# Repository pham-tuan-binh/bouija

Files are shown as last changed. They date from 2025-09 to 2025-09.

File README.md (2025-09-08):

# Bouija

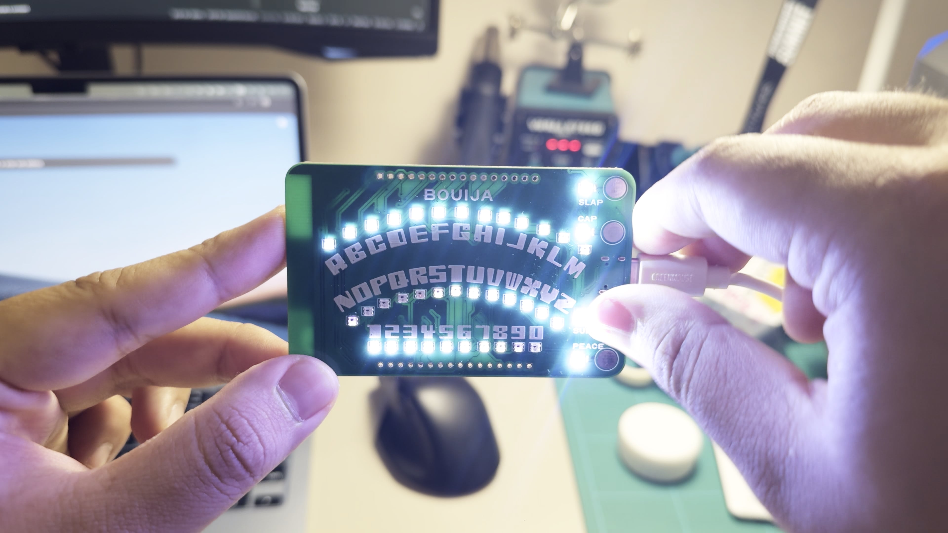
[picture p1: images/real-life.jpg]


A PCB business card that runs an LLM locally with an Ouija board-inspired LED layout.

Watch a video on the design of this business card [here](https://youtu.be/WC3O2cKT8Eo).

**Special thanks to NextPB for sponsoring this project. Check out their website [here](https://www.nextpcb.com?code=Build_With_Binh)**

## Overview

Bouija is a unique business card featuring an ESP32-S3 that runs a local Large Language Model. The device uses 40 individually addressable WS2812B LEDs arranged in an Ouija board pattern to visualize text generation in real-time.

## Specifications

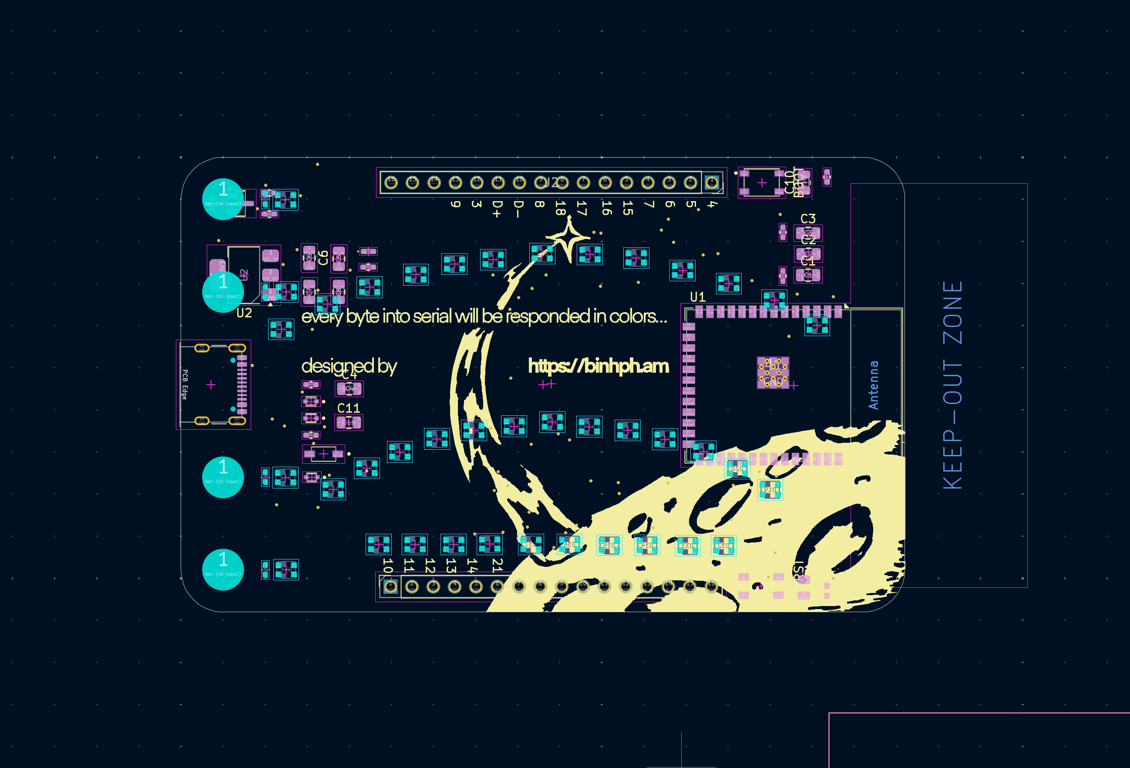
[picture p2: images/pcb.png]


- **PCB Dimensions**: 85mm × 54mm with 3mm corner radius
- **LEDs**: 40 WS2812B LEDs
  - 26 letters (A-Z)
  - 10 numbers (0-9)
  - 4 shortcuts: cap, slap, peace, sup
- **MCU**: ESP32-S3 with 8MB PSRAM and 16MB Flash
- **Layout**: Ouija board arrangement for cultural authenticity

## Firmware Options

### Simple Mode (`/firmware/simple`)

Hard-coded messages with LED visualization and touch interaction.

### LLM Mode (`/firmware/tinyllama`)

Local LLM text generation using [Dave Bennett's ESP32 LLM implementation](https://github.com/DaveBben/esp32-llm). Credit to Dave Bennett for the LLM core - I added the visualization and interaction layer.

## Setup

Requires ESP-IDF toolchain:

```bash
# Navigate to desired firmware directory
cd firmware/tinyllama  # or firmware/simple

# Build and flash
idf.py build
idf.py -p /dev/{DEVICE_PORT} flash
```

## Hardware

The PCB design is available in `/pcb` as a KiCad project.

## Why "Bouija"?

It's a play on "Ouija" + "Binh" (the creator's name) - because what's a business card without a little wordplay? 👻

---

_Running AI on a business card because why not?_

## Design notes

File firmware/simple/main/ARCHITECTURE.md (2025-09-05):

# Code Architecture

This document describes the modular architecture of the ESP32 LED Board Application.

## Module Structure

### 1. **main.c** - Application Entry Point

- **Responsibility**: Application initialization and startup
- **Dependencies**: led.h, app_flow.h
- **Functions**:
  - `app_main()`: Initializes LED strip, sets brightness, and starts application flow

### 2. **led.h/led.c** - LED Hardware Abstraction Layer

- **Responsibility**: LED strip control and animations
- **Dependencies**: ESP-IDF LED strip driver, FreeRTOS
- **Key Functions**:
  - `led_init()`: Initialize LED strip hardware
  - `led_set_led()`: Set individual LED color
  - `led_clear_all()`: Turn off all LEDs
  - `led_show_loading_sequence()`: Rainbow loading animation
  - `led_highlight_buttons()`: Highlight button LEDs
  - `led_show_text_sequence()`: Display text on alphabet LEDs
  - `led_hsv_to_rgb()`: Color space conversion

### 3. **touch.h/touch.c** - Touch Sensor Module

- **Responsibility**: Capacitive touch button detection
- **Dependencies**: ESP-IDF touch pad driver
- **Key Functions**:
  - `touch_init()`: Initialize touch sensors
  - `touch_get_pressed_button()`: Get currently pressed button
  - `touch_is_pressed()`: Check if specific touch pin is pressed
  - `touch_get_button_name()`: Get button name string

### 4. **app_flow.h/app_flow.c** - Application Logic Controller

- **Responsibility**: Application state machine and user interaction flow
- **Dependencies**: led.h, touch.h, FreeRTOS
- **Key Functions**:
  - `app_flow_init()`: Initialize application state machine
  - `app_flow_run()`: Main application loop with state machine
  - `app_flow_get_current_state()`: Get current application state

## Design Principles

### Separation of Concerns

- **Hardware Layer**: LED and touch modules handle only hardware-specific operations
- **Application Layer**: app_flow module handles business logic and state management
- **Entry Point**: main.c handles initialization and startup

### Single Responsibility Principle

- Each module has a single, well-defined responsibility
- LED module only handles LED operations
- Touch module only handles touch detection
- App flow module only handles application logic

### Dependency Inversion

- High-level modules (app_flow) depend on abstractions (interfaces)
- Low-level modules (led, touch) implement specific hardware functionality
- Main module orchestrates the initialization

### State Machine Pattern

- Application flow uses a clear state machine for predictable behavior
- States: INIT → LOADING → BUTTON_HIGHLIGHT → BUTTON_PRESSED → SHOWING_MESSAGE → RETURN_TO_BUTTONS

## Data Flow

```
main.c
  ↓ (initializes)
led.c ← app_flow.c → touch.c
  ↓ (controls)      ↓ (detects)
LED Strip        Touch Pins
```

## Benefits of This Architecture

1. **Maintainability**: Each module can be modified independently
2. **Testability**: Modules can be unit tested in isolation
3. **Reusability**: LED and touch modules can be reused in other projects
4. **Readability**: Clear separation makes code easier to understand
5. **Scalability**: Easy to add new features or modify existing ones

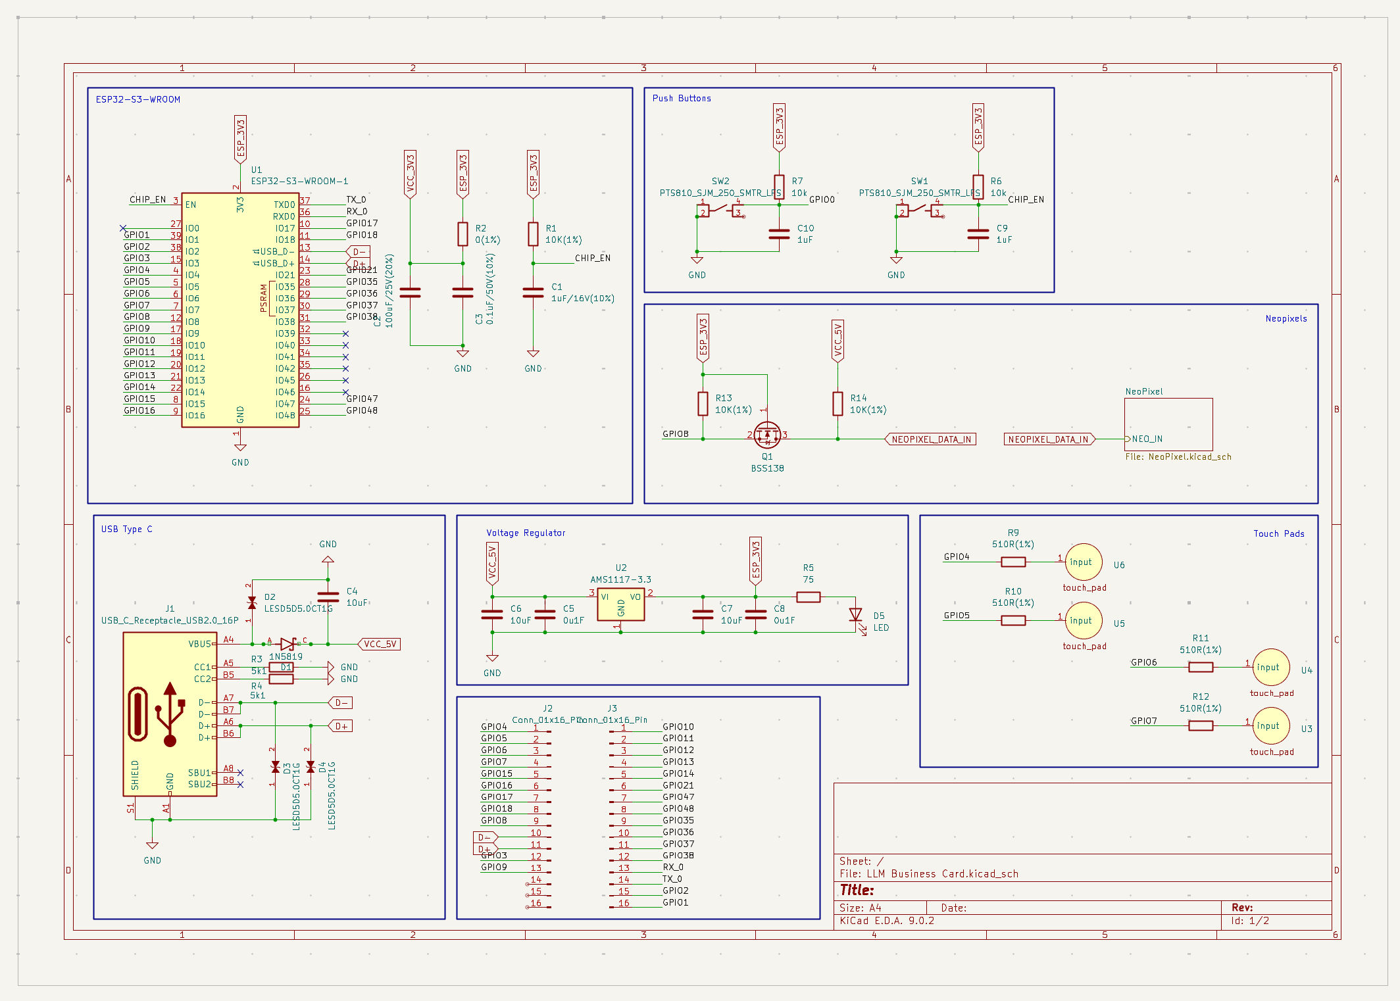
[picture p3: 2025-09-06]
images/schematics.png

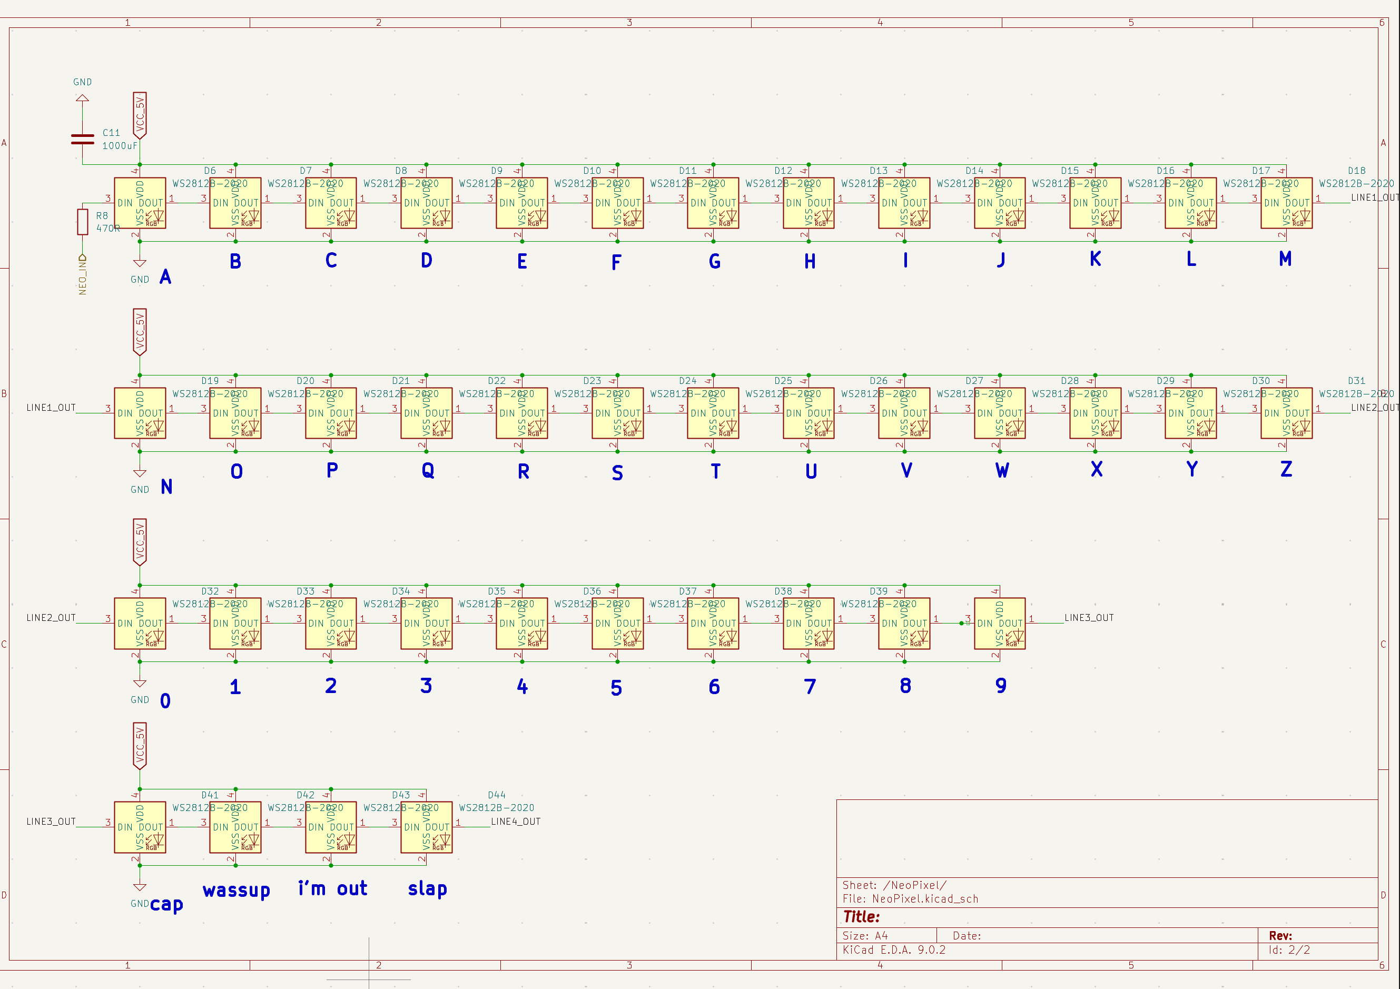
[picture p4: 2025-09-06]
images/leds.png

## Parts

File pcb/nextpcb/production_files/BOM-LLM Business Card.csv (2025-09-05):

MPN | Qty | Designator | value | manufacturer | Category | SKU | Customer Supply | Customer Remark
FS21X105K160ECG | 3 | C1,C9,C10 | 1uF/16V(10%) | Pitts Sales Associates (PSA) | Capacitors | 2500360793
GRM21BR60J107ME15L | 1 | C2 | 100uF/25V(20%) | Murata | Ceramic Capacitors | 1103483307
C0805C104K5RAC7215 | 1 | C3 | 0.1uF/50V(10%) | Yageo | Ceramic Capacitors | -
EMK212BB7106KG-T | 3 | C6,C4,C7 | 10uF | Taiyo Yuden | Capacitors | 1104534147
0805ZC104MAT2A | 2 | C8,C5 | 0u1F | Kyocera | Ceramic Capacitors | 1012110635
EEUFC1E102 | 1 | C11 | 1000uF | Panasonic | Aluminum Electrolytic Capacitors | 1033725480
1N5819 | 1 | D1 | 1N5819 | Vishay | Schottky Diodes | 1100180393
LESD5D5.0CT1G | 3 | D4,D3,D2 | LESD5D5.0CT1G | Leshan Radio Company (LRC) | TVS Diodes | 2500314833
ALED7707TR | 1 | D5 | LED | STMicroelectronics | LED Drivers | 1104102559
WS2812B-2020 | 40 | D14,D25,D30,D39,D38,D34,D12,D13,D28,D44,D36,D15,D26,D10,D32,D9,D6,D20,D35,D8,D7,D31,D29,D17,D43,D46,D18,D19,D27,D37,D24,D42,D33,D22,D40,D23,D21,D41,D16,D11 | WS2812B-2020 | WORLDSEMI | LEDs | 2500385105
TYPE-C16PIN | 1 | J1 | USB_C_Receptacle_USB2.0_16P | SHOU HAN | USB Connectors | 2500412404
 | 2 | J2,J3 | Conn_01x16_Pin
BSS138 | 1 | Q1 | BSS138 | Hottech | MOSFETs | 1112375387
PESD0542U005 | 1 | R2 | 0(1%) | Leiditech | TVS Diodes | 1019351440
CRCW04025K10FKED | 2 | R3,R4 | 5k1 | Vishay | Chip SMD Resistors | 1101330961
PESD0402AV12 | 1 | R5 | 75 | Leiditech | TVS Diodes | 1023216890
RC0402JR-0710KL | 2 | R7,R6 | 10k | Yageo | Chip SMD Resistors | 1101287477
AC0402FR-07470RL | 1 | R8 | 470R | Yageo | Chip SMD Resistors | 1103497035
RK73H1ETTP5100F | 4 | R12,R10,R9,R11 | 510R(1%) | KOA | Chip SMD Resistors | 1105758435
RK73H1ERTTP1002F | 3 | R14,R13,R1 | 10K(1%) | KOA | Chip SMD Resistors | 1111269901
PTS810SJM250SMTRLFS | 2 | SW1,SW2 | PTS810_SJM_250_SMTR_LFS | C&K SYSTEMS | Tactile Switches | 2500325932
ESP32-S3-WROOM-1-N16R8 | 1 | U1 | ESP32-S3-WROOM-1 | Espressif Systems | WiFi Modules | 1112149751
AMS1117-3.3 | 1 | U2 | AMS1117-3.3 | JSMICRO | Linear Voltage Regulators, LDO | 2500288463
 | 4 | U4,U5,U6,U3 | ~

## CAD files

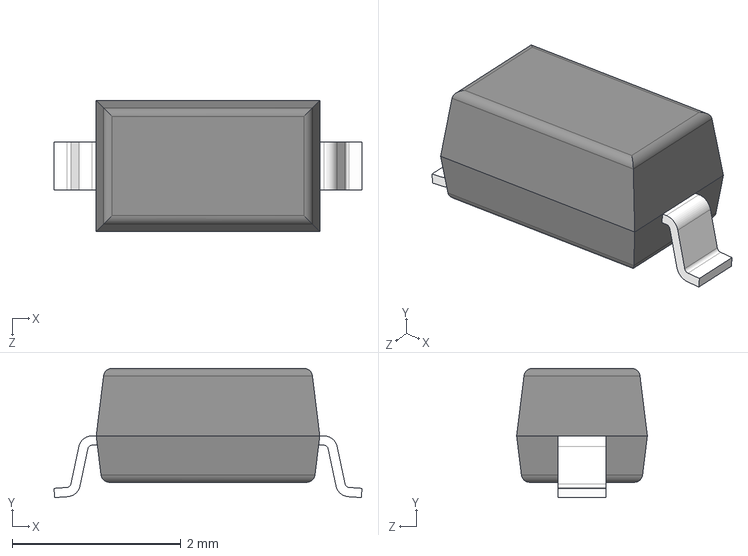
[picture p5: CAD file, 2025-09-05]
pcb/1N5819HW-7-F/1N5819HW-7-F.step
3.65 x 1.53 x 1.55 mm

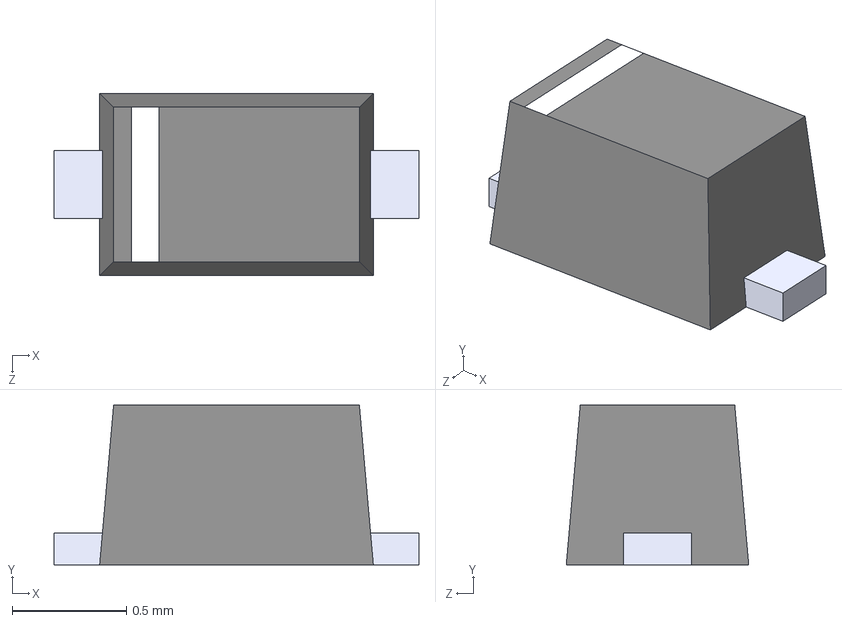
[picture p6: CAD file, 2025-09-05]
pcb/LESD5D5.0CT1G/LESD5D5.0CT1G.step
1.60 x 0.7 x 0.8 mm

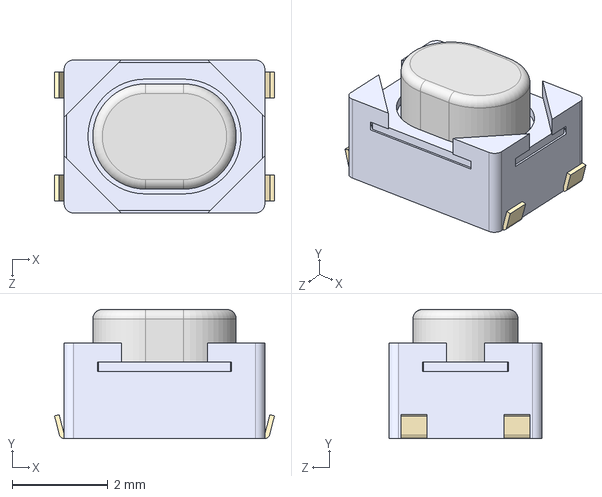
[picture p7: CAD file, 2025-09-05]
pcb/PTS810_SJM_250_SMTR_LFS/PTS810_SJM_250_SMTR_LFS.step
4.60 x 2.70 x 3.20 mm

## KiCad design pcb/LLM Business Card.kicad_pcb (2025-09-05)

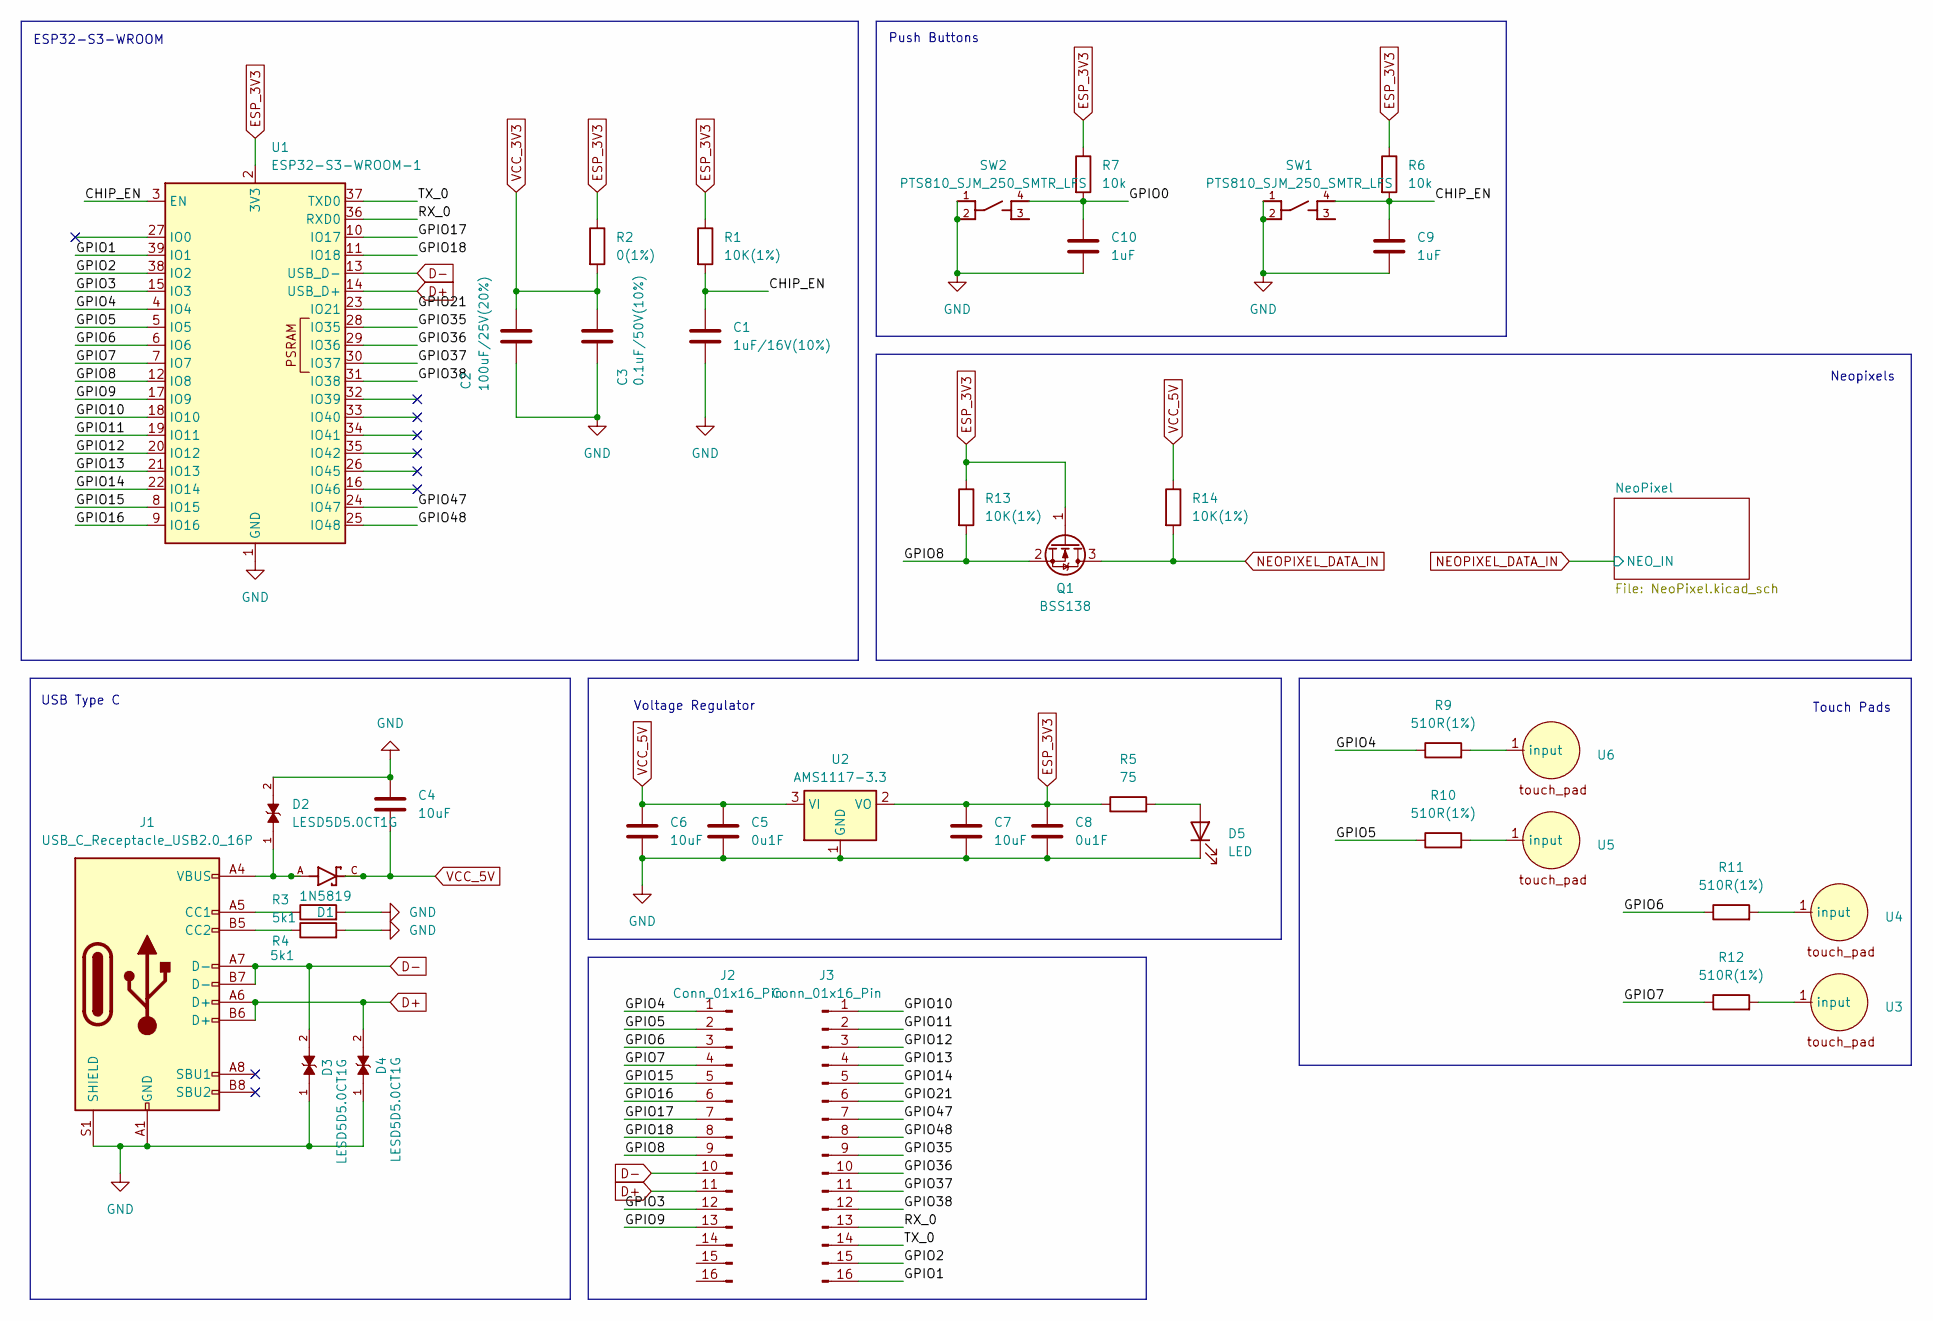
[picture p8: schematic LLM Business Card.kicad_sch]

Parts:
C1: 1uF/16V(10%); C_0805_2012Metric
C2: 100uF/25V(20%); C_0805_2012Metric
C3: 0.1uF/50V(10%); C_0805_2012Metric
C4, C6, C7: 10uF; C_0805_2012Metric
C5, C8: 0u1F; C_0805_2012Metric
C9, C10: 1uF; C_0805_2012Metric
D1: 1N5819; SOD3715X145N; PARTREV 18-2
D2, D3, D4: LESD5D5.0CT1G; TVS_LESD5D5.0CT1G; PARTREV O
D5: LED; LED_0402_1005Metric_Pad0.77x0.64mm_HandSolder
J1: USB_C_Receptacle_USB2.0_16P; USB_C_Receptacle_GCT_USB4105-xx-A_16P_TopMnt_Horizontal
J2, J3: Conn_01x16_Pin; PinSocket_1x16_P2.54mm_Vertical
Q1: BSS138; SOT-23
R1, R13, R14: 10K(1%); R_0402_1005Metric_Pad0.72x0.64mm_HandSolder
R2: 0(1%); R_0402_1005Metric_Pad0.72x0.64mm_HandSolder
R3, R4: 5k1; R_0402_1005Metric_Pad0.72x0.64mm_HandSolder
R5: 75; R_0402_1005Metric_Pad0.72x0.64mm_HandSolder
R6, R7: 10k; R_0402_1005Metric_Pad0.72x0.64mm_HandSolder
R9, R10, R11, R12: 510R(1%); R_0402_1005Metric_Pad0.72x0.64mm_HandSolder
SW1, SW2: PTS810_SJM_250_SMTR_LFS; SW_PTS810_SJM_250_SMTR_LFS
U1: ESP32-S3-WROOM-1
U2: AMS1117-3.3; SOT-223-3_TabPin2
U3, U4, U5, U6: TouchPad

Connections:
/CHIP_EN: C1.1, C9.1, R1.2, R6.2, SW1.4, U1.3 (EN)
/GPIO0: C10.1, R7.2, SW2.4
/GPIO1: J3.16, U1.39 (IO1)
/GPIO2: J3.15, U1.38 (IO2)
/GPIO3: J2.12, U1.15 (IO3)
/GPIO4: J2.1, R9.1, U1.4 (IO4)
/GPIO5: J2.2, R10.1, U1.5 (IO5)
/GPIO6: J2.3, R11.1, U1.6 (IO6)
/GPIO7: J2.4, R12.1, U1.7 (IO7)
/GPIO8: J2.9, Q1.2 (S), R13.2, U1.12 (IO8)
/GPIO9: J2.13, U1.17 (IO9)
/GPIO10: J3.1, U1.18 (IO10)
/GPIO11: J3.2, U1.19 (IO11)
/GPIO12: J3.3, U1.20 (IO12)
/GPIO13: J3.4, U1.21 (IO13)
/GPIO14: J3.5, U1.22 (IO14)
/GPIO15: J2.5, U1.8 (IO15)
/GPIO16: J2.6, U1.9 (IO16)
/GPIO17: J2.7, U1.10 (IO17)
/GPIO18: J2.8, U1.11 (IO18)
/GPIO21: J3.6, U1.23 (IO21)
/GPIO35: J3.9, U1.28 (IO35)
/GPIO36: J3.10, U1.29 (IO36)
/GPIO37: J3.11, U1.30 (IO37)
/GPIO38: J3.12, U1.31 (IO38)
/GPIO47: J3.7, U1.24 (IO47)
/GPIO48: J3.8, U1.25 (IO48)
/RX_0: J3.13, U1.36 (RXD0)
/TX_0: J3.14, U1.37 (TXD0)
D+: D4.2, J1.A6 (D+), J1.B6 (D+), J2.11, U1.14 (USB_D+)
D-: D3.2, J1.A7 (D-), J1.B7 (D-), J2.10, U1.13 (USB_D-)
ESP_3V3: C7.1, C8.1, Q1.1 (G), R1.1, R2.1, R5.1, R6.1, R7.1, R13.1, U1.2 (3V3), U2.2 (VO)
GND: C1.2, C2.2, C3.2, C4.1, C5.2, C6.2, C7.2, C8.2, C9.2, C10.2, D2.2, D3.1, D4.1, D5.1 (K), J1.A1 (GND), J1.A12 (GND), J1.B1 (GND), J1.B12 (GND), J1.S1 (SHIELD), R3.2, R4.2, SW1.1, SW1.2, SW2.1, SW2.2, U1.1 (GND), U1.40 (GND), U1.41 (GND), U2.1 (GND); also elsewhere on the board
NEOPIXEL_DATA_IN: Q1.3 (D), R14.2; also elsewhere on the board
unnamed: D1.A, D2.1, J1.A4 (VBUS), J1.A9 (VBUS), J1.B4 (VBUS), J1.B9 (VBUS)
unnamed: D5.2 (A), R5.2
unnamed: J1.A5 (CC1), R3.1
unnamed: J1.B5 (CC2), R4.1
unnamed: R12.2, U3.1 (input)
unnamed: R11.2, U4.1 (input)
unnamed: R10.2, U5.1 (input)
unnamed: R9.2, U6.1 (input)
VCC_3V3: C2.1, C3.1, R2.2
VCC_5V: C4.2, C5.1, C6.1, D1.C, R14.1, U2.3 (VI); also elsewhere on the board

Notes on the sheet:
Push Buttons
Touch Pads
Voltage Regulator
Neopixels
USB Type C
ESP32-S3-WROOM

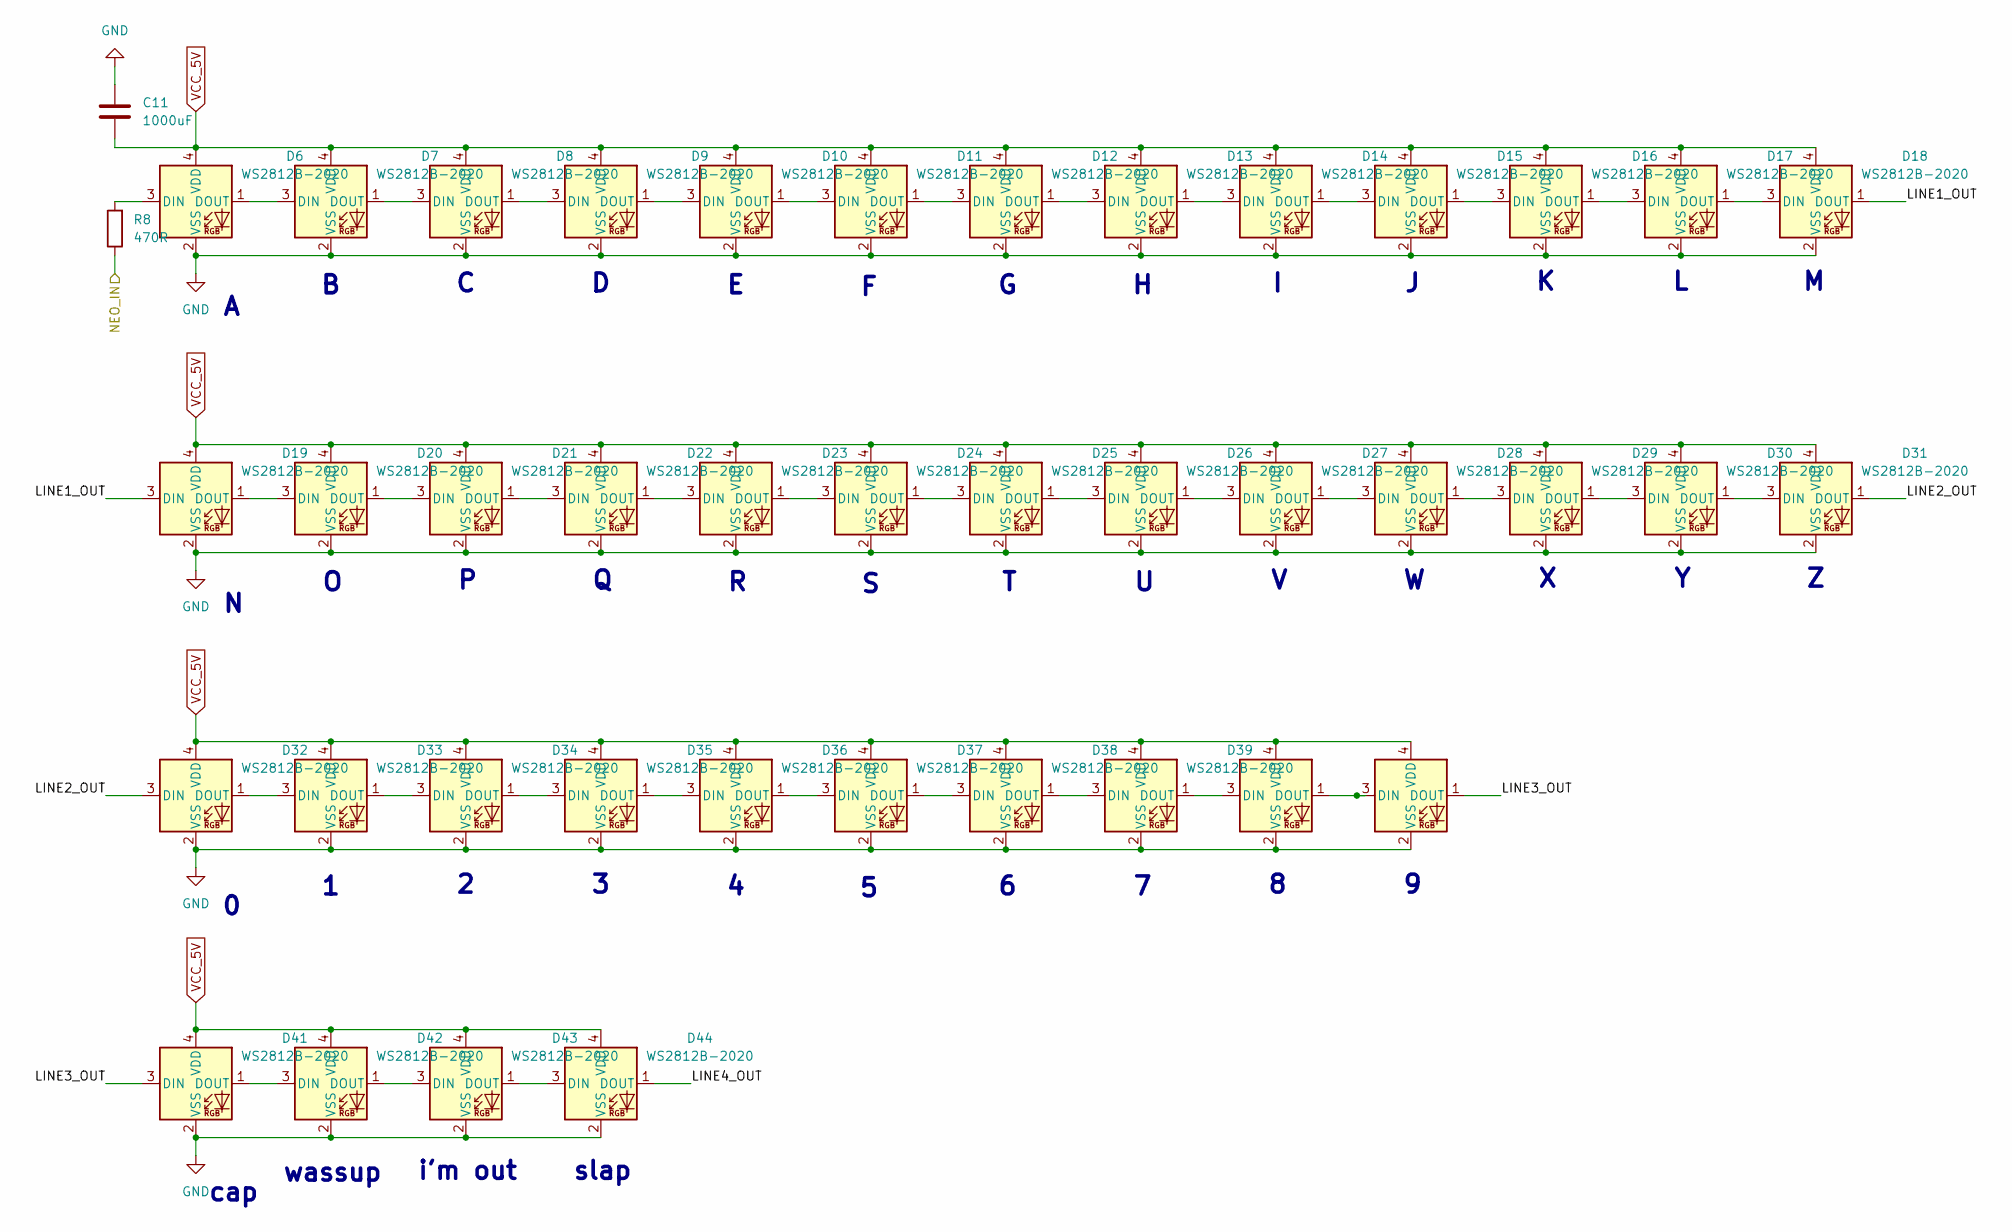
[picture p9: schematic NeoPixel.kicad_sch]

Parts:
C11: 1000uF; C_0805_2012Metric
D6, D7, D8, D9, D10, D11, D12, D13, D14, D15, D16, D17, D18, D19, D20, D21, D22, D23, D24, D25, D26, D27, D28, D29, D30, D31, D32, D33, D34, D35, D36, D37, D38, D39, D40, D41, D42, D43, D44, D46: WS2812B-2020; LED_WS2812B-2020_PLCC4_2.0x2.0mm
R8: 470R; R_0402_1005Metric_Pad0.72x0.64mm_HandSolder

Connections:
/NeoPixel/LINE1_OUT: D18.1 (DOUT), D19.3 (DIN)
/NeoPixel/LINE2_OUT: D31.1 (DOUT), D32.3 (DIN)
/NeoPixel/LINE3_OUT: D41.3 (DIN), D46.1 (DOUT)
/NeoPixel/LINE4_OUT: D44.1 (DOUT)
GND: C11.1, D6.2 (VSS), D7.2 (VSS), D8.2 (VSS), D9.2 (VSS), D10.2 (VSS), D11.2 (VSS), D12.2 (VSS), D13.2 (VSS), D14.2 (VSS), D15.2 (VSS), D16.2 (VSS), D17.2 (VSS), D18.2 (VSS), D19.2 (VSS), D20.2 (VSS), D21.2 (VSS), D22.2 (VSS), D23.2 (VSS), D24.2 (VSS), D25.2 (VSS), D26.2 (VSS), D27.2 (VSS), D28.2 (VSS), D29.2 (VSS), D30.2 (VSS), D31.2 (VSS), D32.2 (VSS), D33.2 (VSS), D34.2 (VSS), D35.2 (VSS), D36.2 (VSS), D37.2 (VSS), D38.2 (VSS), D39.2 (VSS), D40.2 (VSS), D41.2 (VSS), D42.2 (VSS), D43.2 (VSS), D44.2 (VSS), D46.2 (VSS); also elsewhere on the board
NEOPIXEL_DATA_IN: R8.1; also elsewhere on the board
unnamed: D6.3 (DIN), R8.2
unnamed: D6.1 (DOUT), D7.3 (DIN)
unnamed: D7.1 (DOUT), D8.3 (DIN)
unnamed: D8.1 (DOUT), D9.3 (DIN)
unnamed: D9.1 (DOUT), D10.3 (DIN)
unnamed: D10.1 (DOUT), D11.3 (DIN)
unnamed: D11.1 (DOUT), D12.3 (DIN)
unnamed: D12.1 (DOUT), D13.3 (DIN)
unnamed: D13.1 (DOUT), D14.3 (DIN)
unnamed: D14.1 (DOUT), D15.3 (DIN)
unnamed: D15.1 (DOUT), D16.3 (DIN)
unnamed: D16.1 (DOUT), D17.3 (DIN)
unnamed: D17.1 (DOUT), D18.3 (DIN)
unnamed: D19.1 (DOUT), D20.3 (DIN)
unnamed: D20.1 (DOUT), D21.3 (DIN)
unnamed: D21.1 (DOUT), D22.3 (DIN)
unnamed: D22.1 (DOUT), D23.3 (DIN)
unnamed: D23.1 (DOUT), D24.3 (DIN)
unnamed: D24.1 (DOUT), D25.3 (DIN)
unnamed: D25.1 (DOUT), D26.3 (DIN)
unnamed: D26.1 (DOUT), D27.3 (DIN)
unnamed: D27.1 (DOUT), D28.3 (DIN)
unnamed: D28.1 (DOUT), D29.3 (DIN)
unnamed: D29.1 (DOUT), D30.3 (DIN)
unnamed: D30.1 (DOUT), D31.3 (DIN)
unnamed: D32.1 (DOUT), D33.3 (DIN)
unnamed: D33.1 (DOUT), D34.3 (DIN)
unnamed: D34.1 (DOUT), D35.3 (DIN)
unnamed: D35.1 (DOUT), D36.3 (DIN)
unnamed: D36.1 (DOUT), D37.3 (DIN)
unnamed: D37.1 (DOUT), D38.3 (DIN)
unnamed: D38.1 (DOUT), D39.3 (DIN)
unnamed: D39.1 (DOUT), D40.3 (DIN)
unnamed: D40.1 (DOUT), D46.3 (DIN)
unnamed: D41.1 (DOUT), D42.3 (DIN)
unnamed: D42.1 (DOUT), D43.3 (DIN)
unnamed: D43.1 (DOUT), D44.3 (DIN)
VCC_5V: C11.2, D6.4 (VDD), D7.4 (VDD), D8.4 (VDD), D9.4 (VDD), D10.4 (VDD), D11.4 (VDD), D12.4 (VDD), D13.4 (VDD), D14.4 (VDD), D15.4 (VDD), D16.4 (VDD), D17.4 (VDD), D18.4 (VDD), D19.4 (VDD), D20.4 (VDD), D21.4 (VDD), D22.4 (VDD), D23.4 (VDD), D24.4 (VDD), D25.4 (VDD), D26.4 (VDD), D27.4 (VDD), D28.4 (VDD), D29.4 (VDD), D30.4 (VDD), D31.4 (VDD), D32.4 (VDD), D33.4 (VDD), D34.4 (VDD), D35.4 (VDD), D36.4 (VDD), D37.4 (VDD), D38.4 (VDD), D39.4 (VDD), D40.4 (VDD), D41.4 (VDD), D42.4 (VDD), D43.4 (VDD), D44.4 (VDD), D46.4 (VDD); also elsewhere on the board

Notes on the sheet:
i'm out
wassup
cap
slap

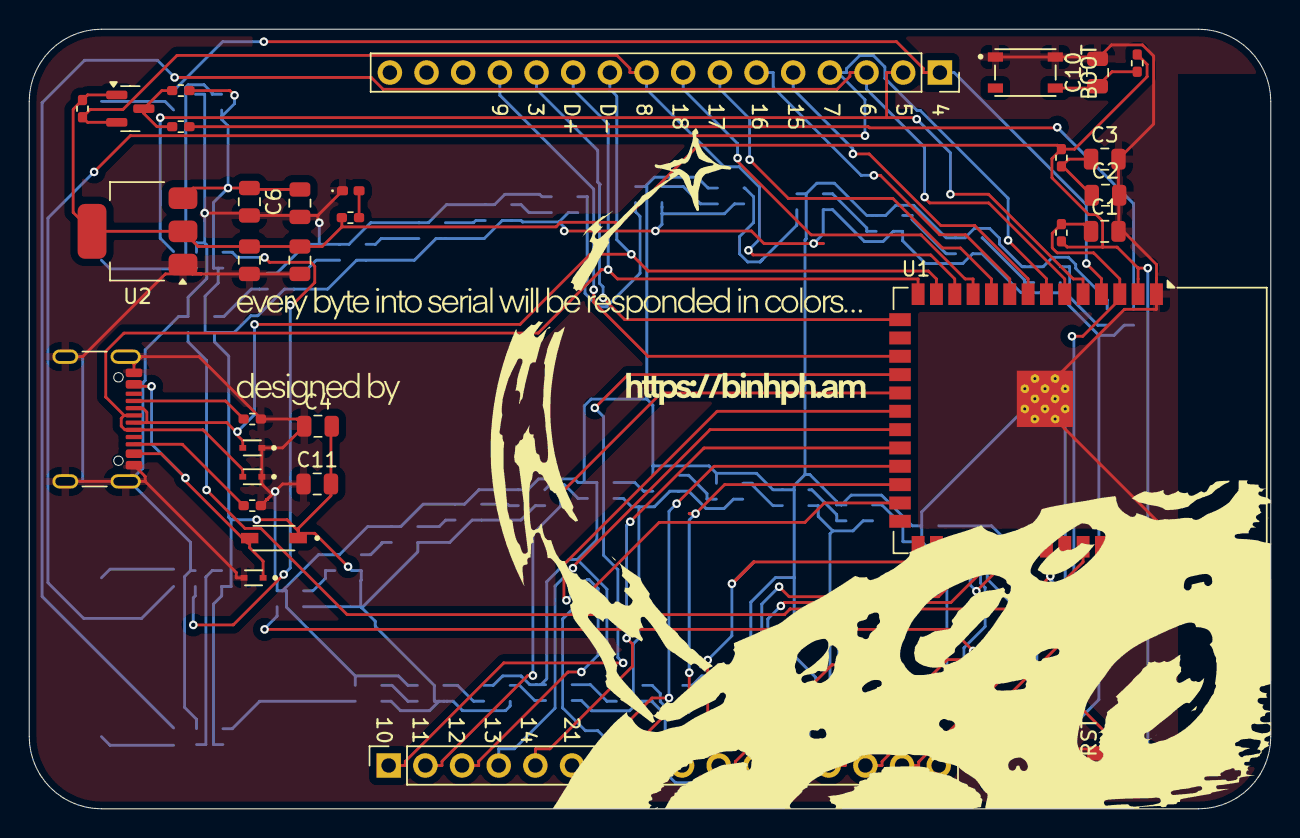
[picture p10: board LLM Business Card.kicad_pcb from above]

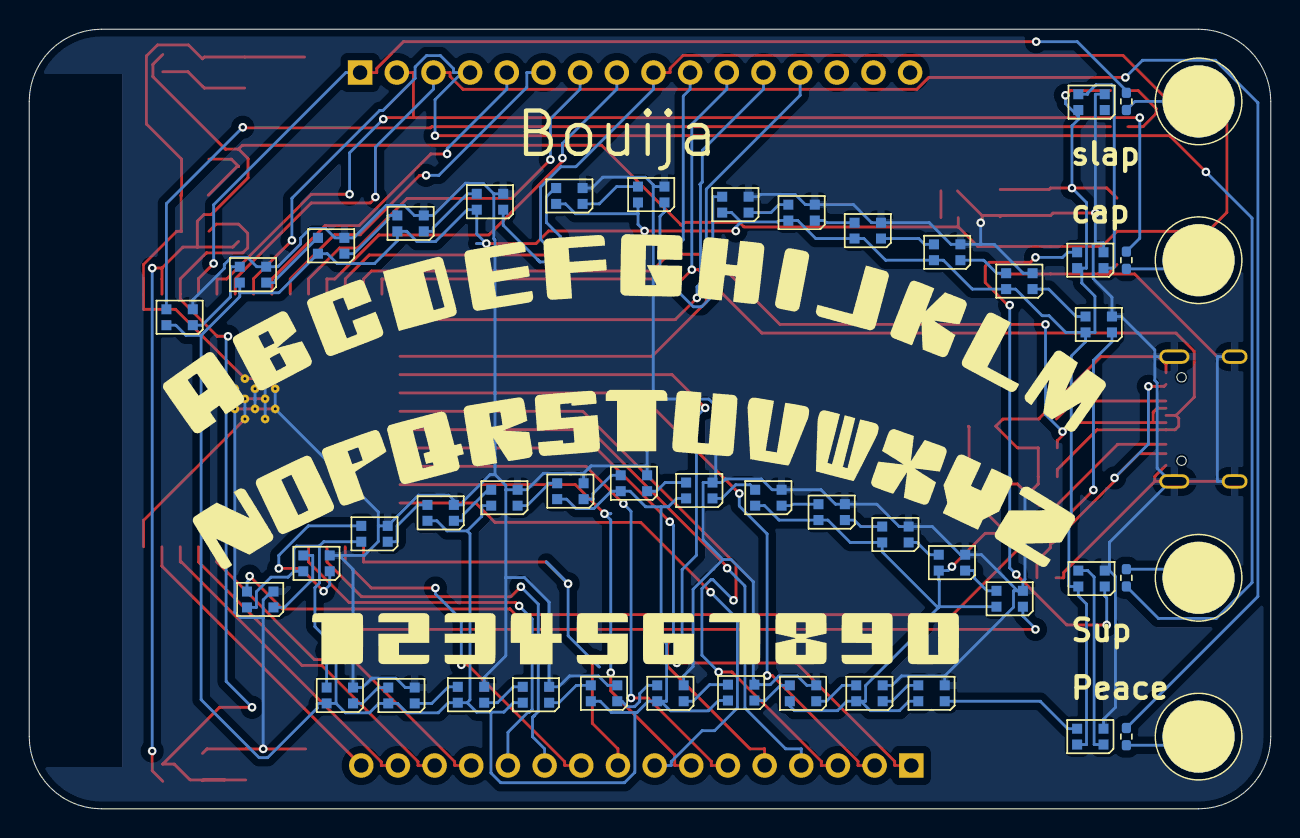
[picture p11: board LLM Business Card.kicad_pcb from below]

Board: 2 copper layers, 86.0 x 54.0 mm, 84 parts (49 on the bottom side), 84 nets.

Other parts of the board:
Moon: LOGO; FrontSilk
Ouija: LOGO; Ouija

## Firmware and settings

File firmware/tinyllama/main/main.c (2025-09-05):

#include <stdio.h>
#include <inttypes.h>
#include "esp_spiffs.h"
#include "sdkconfig.h"
#include "esp_err.h"
#include "esp_log.h"
#include <time.h>
#include "llm.h"
#include "led.h"
#include <string.h>

static const char *TAG = "MAIN";


/**
 * @brief intializes SPIFFS storage
 * 
 */
void init_storage(void)
{

    ESP_LOGI(TAG, "Initializing SPIFFS");

    esp_vfs_spiffs_conf_t conf = {
        .base_path = "/data",
        .partition_label = NULL,
        .max_files = 5,
        .format_if_mount_failed = false};

    esp_err_t ret = esp_vfs_spiffs_register(&conf);

    if (ret != ESP_OK)
    {
        if (ret == ESP_FAIL)
        {
            ESP_LOGE(TAG, "Failed to mount or format filesystem");
        }
        else if (ret == ESP_ERR_NOT_FOUND)
        {
            ESP_LOGE(TAG, "Failed to find SPIFFS partition");
        }
        else
        {
            ESP_LOGE(TAG, "Failed to initialize SPIFFS (%s)", esp_err_to_name(ret));
        }
        return;
    }

    size_t total = 0, used = 0;
    ret = esp_spiffs_info(NULL, &total, &used);
    if (ret != ESP_OK)
    {
        ESP_LOGE(TAG, "Failed to get SPIFFS partition information (%s)", esp_err_to_name(ret));
    }
    else
    {
        ESP_LOGI(TAG, "Partition size: total: %d, used: %d", total, used);
    }
}


/**
 * @brief Callbacks once generation is done
 * 
 * @param tk_s The number of tokens per second generated
 */
void generate_complete_cb(float tk_s)
{
    ESP_LOGI(TAG, "Generation complete: %.2f tok/s", tk_s);
}

/**
 * @brief Callback for each generated token - displays on LED strip
 * 
 * @param token_str The generated token string
 */
void on_token_generated(const char* token_str)
{
    if (!token_str) return;
    
    ESP_LOGI(TAG, "Token generated: '%s' (len=%d)", token_str, strlen(token_str));
    
    // Debug: print each character's ASCII value
    for (int i = 0; i < strlen(token_str); i++) {
        ESP_LOGI(TAG, "  Char %d: '%c' (ASCII %d)", i, token_str[i], (int)token_str[i]);
    }
    
    // Display the token on LED strip
    // For single characters, show directly
    if (strlen(token_str) == 1) {
        led_show_character(token_str[0]);
    } else {
        // For multi-character tokens, show each character sequentially
        led_show_text_sequence(token_str, LED_COLOR_WHITE);
    }
}

void app_main(void)
{
    ESP_LOGI(TAG, "Starting ESP32 LLM application");
    ESP_LOGI(TAG, "Loading Model...");
    init_storage();
    
    // Initialize LED strip
    ESP_LOGI(TAG, "Initializing LED strip...");
    esp_err_t ret = led_init();
    if (ret != ESP_OK) {
        ESP_LOGE(TAG, "Failed to initialize LED strip: %s", esp_err_to_name(ret));
    } else {
        ESP_LOGI(TAG, "LED strip initialized successfully");
        
        // Set LED brightness (0-255, where 255 is maximum brightness)
        // You can adjust this value to control the overall brightness
        led_set_brightness(128);  // 50% brightness - adjust as needed
        ESP_LOGI(TAG, "LED brightness set to %d", led_get_brightness());
    }

    // default parameters
    char *checkpoint_path = "/data/stories260K.bin"; // e.g. out/model.bin
    char *tokenizer_path = "/data/tok512.bin";
    float temperature = 1.0f;        // 0.0 = greedy deterministic. 1.0 = original. don't set higher
    float topp = 0.9f;               // top-p in nucleus sampling. 1.0 = off. 0.9 works well, but slower
    int steps = 500;                  // number of steps to run for
    char *prompt = "Once upon a time"; // prompt string
    unsigned long long rng_seed = 0; // seed rng with time by default

    // parameter validation/overrides
    if (rng_seed <= 0)
        rng_seed = (unsigned int)time(NULL);

    // build the Transformer via the model .bin file
    Transformer transformer;
    ESP_LOGI(TAG, "LLM Path is %s", checkpoint_path);
    build_transformer(&transformer, checkpoint_path);
    if (steps == 0 || steps > transformer.config.seq_len)
        steps = transformer.config.seq_len; // override to ~max length

    // build the Tokenizer via the tokenizer .bin file
    Tokenizer tokenizer;
    build_tokenizer(&tokenizer, tokenizer_path, transformer.config.vocab_size);

    // build the Sampler
    Sampler sampler;
    build_sampler(&sampler, transformer.config.vocab_size, temperature, topp, rng_seed);

    // run!
    ESP_LOGI(TAG, "Starting text generation with prompt: '%s'", prompt);
    generate(&transformer, &tokenizer, &sampler, prompt, steps, &generate_complete_cb, &on_token_generated);
}

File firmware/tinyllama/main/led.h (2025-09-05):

#ifndef LED_H
#define LED_H

#include "esp_err.h"
#include "led_strip.h"
#include "freertos/FreeRTOS.h"
#include "freertos/task.h"

// LED strip configuration
#define LED_STRIP_GPIO 8
#define LED_STRIP_COUNT 40
#define LED_STRIP_MODEL LED_MODEL_WS2812

// Touch input configuration
#define TOUCH_GPIO_SLAP 4
#define TOUCH_GPIO_CAP 5
#define TOUCH_GPIO_SUP 6
#define TOUCH_GPIO_PEACE 7
#define TOUCH_THRESHOLD 70000

// Special LED indices for slap/cap/sup/peace
#define LED_SLAP 39
#define LED_CAP 38
#define LED_SUP 37
#define LED_PEACE 36

// Color definitions
#define LED_COLOR_OFF 0x000000
#define LED_COLOR_RED 0xFF0000
#define LED_COLOR_GREEN 0x00FF00
#define LED_COLOR_BLUE 0x0000FF
#define LED_COLOR_WHITE 0xFFFFFF
#define LED_COLOR_YELLOW 0xFFFF00
#define LED_COLOR_CYAN 0x00FFFF
#define LED_COLOR_MAGENTA 0xFF00FF

// Animation timing
#define LED_DISPLAY_DURATION_MS 1000
#define LED_CLEAR_DELAY_MS 100

// Brightness settings
#define LED_MAX_BRIGHTNESS 128  // Maximum brightness (0-255)
#define LED_DEFAULT_BRIGHTNESS 64  // Default brightness (0-255)

// Function declarations
esp_err_t led_init(void);
esp_err_t led_deinit(void);
esp_err_t led_clear_all(void);
esp_err_t led_set_color(uint32_t color);
esp_err_t led_set_led(int index, uint32_t color);
esp_err_t led_show_character(char c);
esp_err_t led_show_word(const char *word);
esp_err_t led_show_text_sequence(const char *text, uint32_t color);
esp_err_t led_animate_text(const char *text, uint32_t color, int delay_ms);

// Character to LED index mapping
int char_to_led_index(char c);
int word_to_led_index(const char *word);

// Utility functions
uint32_t led_color_from_rgb(uint8_t r, uint8_t g, uint8_t b);
uint32_t led_hsv_to_rgb(uint16_t h, uint8_t s, uint8_t v);
esp_err_t led_fade_in_out(int index, uint32_t color, int duration_ms);

// Brightness control functions
esp_err_t led_set_brightness(uint8_t brightness);
uint8_t led_get_brightness(void);
uint32_t led_apply_brightness(uint32_t color, uint8_t brightness);

// Loading sequence functions
esp_err_t led_loading_sequence(void);
esp_err_t led_pulse_special_leds(void);
esp_err_t led_device_init_sequence(void);

#endif // LED_H
